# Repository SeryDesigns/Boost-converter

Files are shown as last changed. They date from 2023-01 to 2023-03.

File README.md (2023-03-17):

# Boost converter

## Project status 
Manufactured, assembled, not tested yet

## Project overview

Small boost converter PCB that can be used for small projects, the converter is based on MT3608 IC, which is a cheap IC manufactured by different chinese companies.
The input voltage can be from 2V to 24V, the output can be set up to 28V.
According to the datasheet, the output current limited by the switch is 4A, I've not tested the circuit yet but for high currents thermal dissipation must be taken into account. The datasheet doesn't specify thermal resistance so it will be hard to assess the real acceptable current, I'll update about my findings after some inital tests.\
The switching frequancy of the converter is 1.2MHz.\
The IC has undervoltage lockout, current limiting, thermal and overload protection 

The dimension of the PCB are 33mm X 15mm, it is a 2 layers PCB with compoenents assembled only on the TOP layer

Top view - \
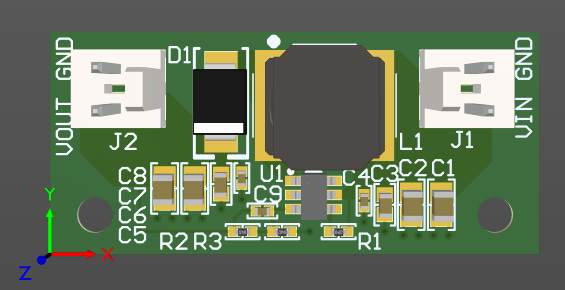
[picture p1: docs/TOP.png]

\
Bottom view -  \
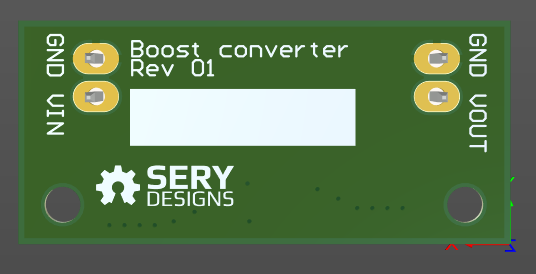
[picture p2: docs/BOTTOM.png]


I've created a short time lapse video of the design process, you can click the link below to check it out on my YouTube channel \
Boost converter PCB design in 5 minutes (time lapse) (https://youtu.be/zZR8q_p8QZo)

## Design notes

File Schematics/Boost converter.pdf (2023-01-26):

# Boost converter

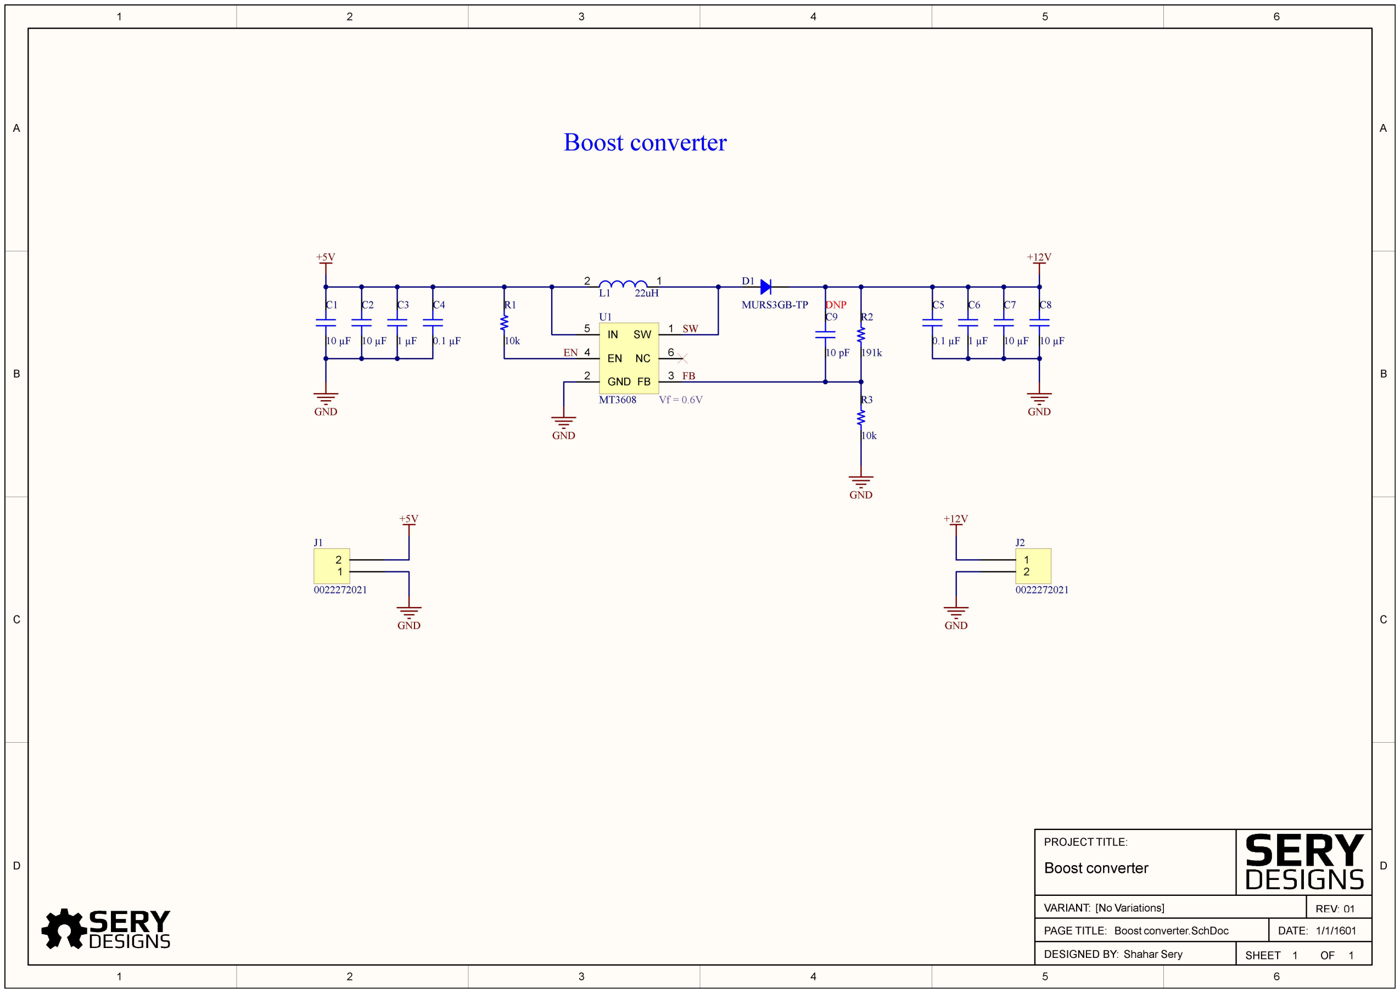
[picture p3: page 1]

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
Boost converter.SchDoc

SHEET | OF 1

REV:

PROJECT TITLE:

## Boost converter

1

VARIANT:

PAGE TITLE: | DATE:

DESIGNED BY:

[No Variations] | 01
| 1/1/1601

Shahar Sery

SW | 1
GND 2 | FB | 3

EN 4

IN 5

NC 6

U1

MT3608

GND

+5V | +12V

### 10 µF

C1

### 10 µF

C2

### 1 µF

C3

### 0.1 µF

C4

GND

### 10 µF

C8

### 10 µF

C7

### 1 µF

C6

### 0.1 µF

C5

GND

10k

R1

Vf = 0.6V

2 1
L1 22uH

10k

R3

191k

R2

GND

D1

MURS3GB-TP

### 10 pF

C9

DNP

1

2

J1

0022272021

1
2

J2

0022272021

GND

+5V | +12V

GND

SW

FB

EN

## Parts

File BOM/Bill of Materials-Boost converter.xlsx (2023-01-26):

Line # | Designator | Name | Manufacturer Part Number 1 | Description | Quantity | Manufacturer 1 | Manufacturer Lifecycle 1 | Supplier 1 | Supplier Part Number 1 | Supplier Unit Price 1 | Supplier Subtotal 1
 | C1, C2, C7, C8 | 10 µF | GRM21BR61H106ME43L | CAP CER 10UF 50V X5R 0805 | 4 | Murata | Unknown | Digi-Key | 490-18664-1-ND | 0.39 | 1.56
 | C3, C6 | 1 µF | UMK107AB7105KA-T | CAP CER 1UF 50V X7R 0603 | 2 | Taiyo Yuden | Unknown | Digi-Key | 587-3247-1-ND | 0.26 | 0.52
 | C4, C5 | 0.1 µF | CGA2B3X7R1H104M050BB | CAP CER 0.1UF 50V X7R 0402 | 2 | TDK | Unknown | DigiKey | 445-12271-1-ND
 | C9 | 10 pF | CL05C100JB5NNNC | CAP CER 10PF 50V C0G/NP0 0402 | 1 | Samsung | Unknown | Digi-Key | 1276-1139-1-ND | 0.1 | 0.1
 | D1 | MURS3GB-TP | MURS3GB-TP | 3A,400V, SUPER FAST RECOVERY REC | 1 | MCC | Unknown | Digi-Key | MURS3GB-TPMSCT-ND | 0.51 | 0.51
 | J1, J2 | 0022272021 | 22-27-2021 | CONN HEADER VERT 2POS 2.54MM | 2 | Molex | Unknown | Digi-Key | WM4111-ND | 0.3 | 0.6
 | L1 | 22uH | NRS8040T220MJGJV | Inductor, Fixed, SMD, 22µH, 2.2A | 1 | Taiyo Yuden | Unknown | Digi-Key | 587-3655-2-ND | 0.27472 | 274.72
 | R1, R3 | 10k | RE0402FRE0710KL | RES SMD 10K OHM 1% 1/16W 0402 | 2 | Yageo | Unknown | Digi-Key | 13-RE0402FRE0710KLCT-ND | 0.1 | 0.2
 | R2 | 191k | AC0402FR-07191KL | RES SMD 191K OHM 1% 1/16W 0402 | 1 | Yageo | Unknown | Digi-Key | 13-AC0402FR-07191KLCT-ND | 0.1 | 0.1
 | U1 | MT3608 |  |  | 1
